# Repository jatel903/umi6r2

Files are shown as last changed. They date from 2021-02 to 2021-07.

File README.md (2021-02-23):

# UMI6R2
## Universal modbus inputs module
###### jatel.sk
**Specification:**  
Supply: 12 - 30V / 50mA  
Core: Arduino Nano  
Number of inputs: 6  
Input types: TTL / TTL with pull-up 2k2 / 0-10V / 1-10V / 0-20mA / 4-20mA  
Number of outputs: 2  
Output types: relay contact 10A/240VAC  
Communication: Modbus RTU 485  
Mounting: [DIN 4M](https://www.tme.eu/sk/en/details/4mh53_5/din-rail-mounting-enclosures/italtronic/)  

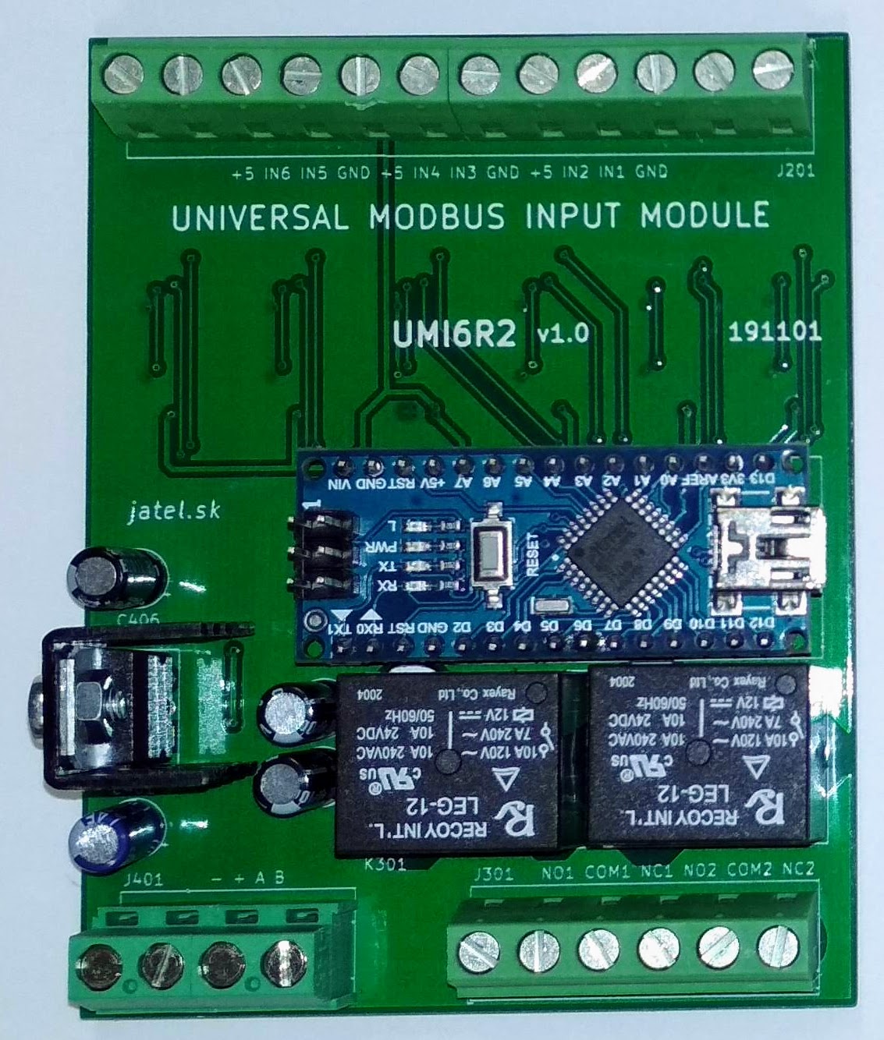
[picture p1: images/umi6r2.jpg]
  

#### Description
Low cost universal modbus controll unit for low cost sensors and actuators from China:  
[NTC](https://www.aliexpress.com/item/1005001645557005.html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,searchweb201602_,searchweb201603_)  
 [Hall Flow Sensor](https://www.aliexpress.com/item/1005001652070023.html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,searchweb201602_,searchweb201603_)  
[DHT22](https://www.aliexpress.com/item/32759901711.html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,searchweb201602_,searchweb201603_)  
[DS18B20](https://www.aliexpress.com/item/4000895660165.html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,searchweb201602_,searchweb201603_)  
[Pressure Sensor](https://www.aliexpress.com/item/1447040260.html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,searchweb201602_,searchweb201603_)  
[Electric Valve](https://www.aliexpress.com/item/4000279793000.html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,searchweb201602_,searchweb201603_)  
[Electric Solenoid Valve](https://www.aliexpress.com/item/4000067341651.html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,searchweb201602_,searchweb201603_)  
etc...

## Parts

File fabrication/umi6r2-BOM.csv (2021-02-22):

Reference | Quantity | Value | Footprint | Datasheet
A401 | 1 | Arduino_Nano_v3.x | Module:Arduino_Nano | http://www.mouser.com/pdfdocs/Gravitech_Arduino_Nano3_0.pdf
C201 C202 C203 C213 C214 C215 | 6 | 100p | Capacitor_SMD:C_0805_2012Metric_Pad1.15x1.40mm_HandSolder | ~
C210 C204 C205 C211 C206 C207 C212 C208 C209 C222 C216 C217 C223 C218 C219 C224 C220 C221 C405 C402 C403 C408 C407 C404 | 24 | 100n | Capacitor_SMD:C_0805_2012Metric_Pad1.15x1.40mm_HandSolder | ~
C301 C302 C406 | 3 | 100u/16V | Capacitor_THT:CP_Radial_D5.0mm_P2.50mm | ~
C401 | 1 | 47u/35V | Capacitor_THT:CP_Radial_D5.0mm_P2.50mm | ~
D201 D202 D203 D204 D205 D206 | 6 | BZT52B5V6 | Diode_SMD:D_SOD-123 | https://diotec.com/tl_files/diotec/files/pdf/datasheets/bzt52b2v4.pdf
D301 D302 | 2 | TS4148 | Diode_SMD:D_0805_2012Metric
D401 | 1 | B140-E3 | Diode_SMD:D_SMA | http://www.vishay.com/docs/88946/b120.pdf
F201 F202 F203 F204 F205 F206 | 6 | SN005 | Resistor_SMD:R_1206_3216Metric_Pad1.42x1.75mm_HandSolder | ~
J201 | 1 | INPUTS | TerminalBlock_Phoenix:TerminalBlock_Phoenix_MKDS-1,5-12-5.08_1x12_P5.08mm_Horizontal | ~
J301 | 1 | OUTPUTS | TerminalBlock_Phoenix:TerminalBlock_Phoenix_MKDS-1,5-6-5.08_1x06_P5.08mm_Horizontal | ~
J401 | 1 | Pwr | TerminalBlock_Phoenix:TerminalBlock_Phoenix_MKDS-1,5-4-5.08_1x04_P5.08mm_Horizontal | ~
K301 K302 | 2 | LEG-12 | jt_relay:Relay_SPDT_RAYEX ELEC_LEG_Series_Form_1C | https://www.tme.eu/Document/311affc211749c2a4c93ad074af62b72/LEG-SERIES.pdf
Q301 Q302 | 2 | BC847 | Package_TO_SOT_SMD:SOT-23 | http://www.infineon.com/dgdl/Infineon-BC847SERIES_BC848SERIES_BC849SERIES_BC850SERIES-DS-v01_01-en.pdf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
R202 R201 R204 R203 R206 R205 R226 R225 R228 R227 R230 R229 | 12 | 100R | Resistor_SMD:R_0805_2012Metric_Pad1.15x1.40mm_HandSolder | ~
R207 R210 R212 R215 R217 R220 R231 R234 R236 R239 R241 R244 R401 | 13 | 12k | Resistor_SMD:R_0805_2012Metric_Pad1.15x1.40mm_HandSolder | ~
R209 R208 R214 R213 R219 R218 R233 R232 R238 R237 R243 R242 | 12 | 3k3 | Resistor_SMD:R_0805_2012Metric_Pad1.15x1.40mm_HandSolder | ~
R211 R216 R221 R235 R240 R245 | 6 | 51R | Resistor_SMD:R_0805_2012Metric_Pad1.15x1.40mm_HandSolder | ~
R222 R223 R224 R246 R247 R248 | 6 | 2R7 | Resistor_SMD:R_0805_2012Metric_Pad1.15x1.40mm_HandSolder | ~
R303 R304 | 2 | 330R | Resistor_SMD:R_0805_2012Metric_Pad1.15x1.40mm_HandSolder | ~
R305 R301 R306 R302 | 4 | 4k7 | Resistor_SMD:R_0805_2012Metric_Pad1.15x1.40mm_HandSolder | ~
U201 U202 U203 U204 U205 U206 | 6 | 74HC4052 | Package_SO:SOIC-16_3.9x9.9mm_P1.27mm | http://www.ti.com/lit/ds/symlink/cd4052b.pdf
U401 | 1 | MAX485E | Package_SO:SOIC-8_3.9x4.9mm_P1.27mm | https://datasheets.maximintegrated.com/en/ds/MAX1487E-MAX491E.pdf
U402 | 1 | LM7812_TO220 | Package_TO_SOT_THT:TO-220-3_Vertical | http://www.fairchildsemi.com/ds/LM/LM7805.pdf
U403 | 1 | 74HC595 | Package_SO:SOIC-16_3.9x9.9mm_P1.27mm | http://www.ti.com/lit/ds/symlink/sn74hc595.pdf

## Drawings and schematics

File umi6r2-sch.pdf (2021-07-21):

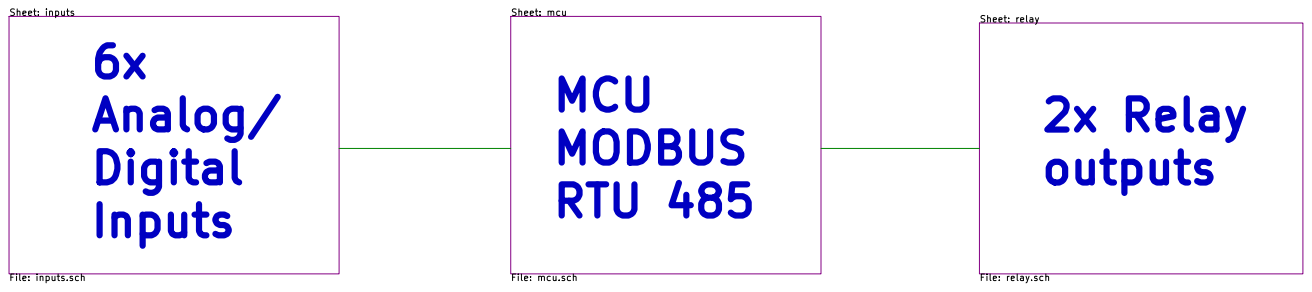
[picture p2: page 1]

File: relay.sch Sheet: mcu File: mcu.schMCU

Id: 1/4 Title: File: umi6r2.sch Sheet: /

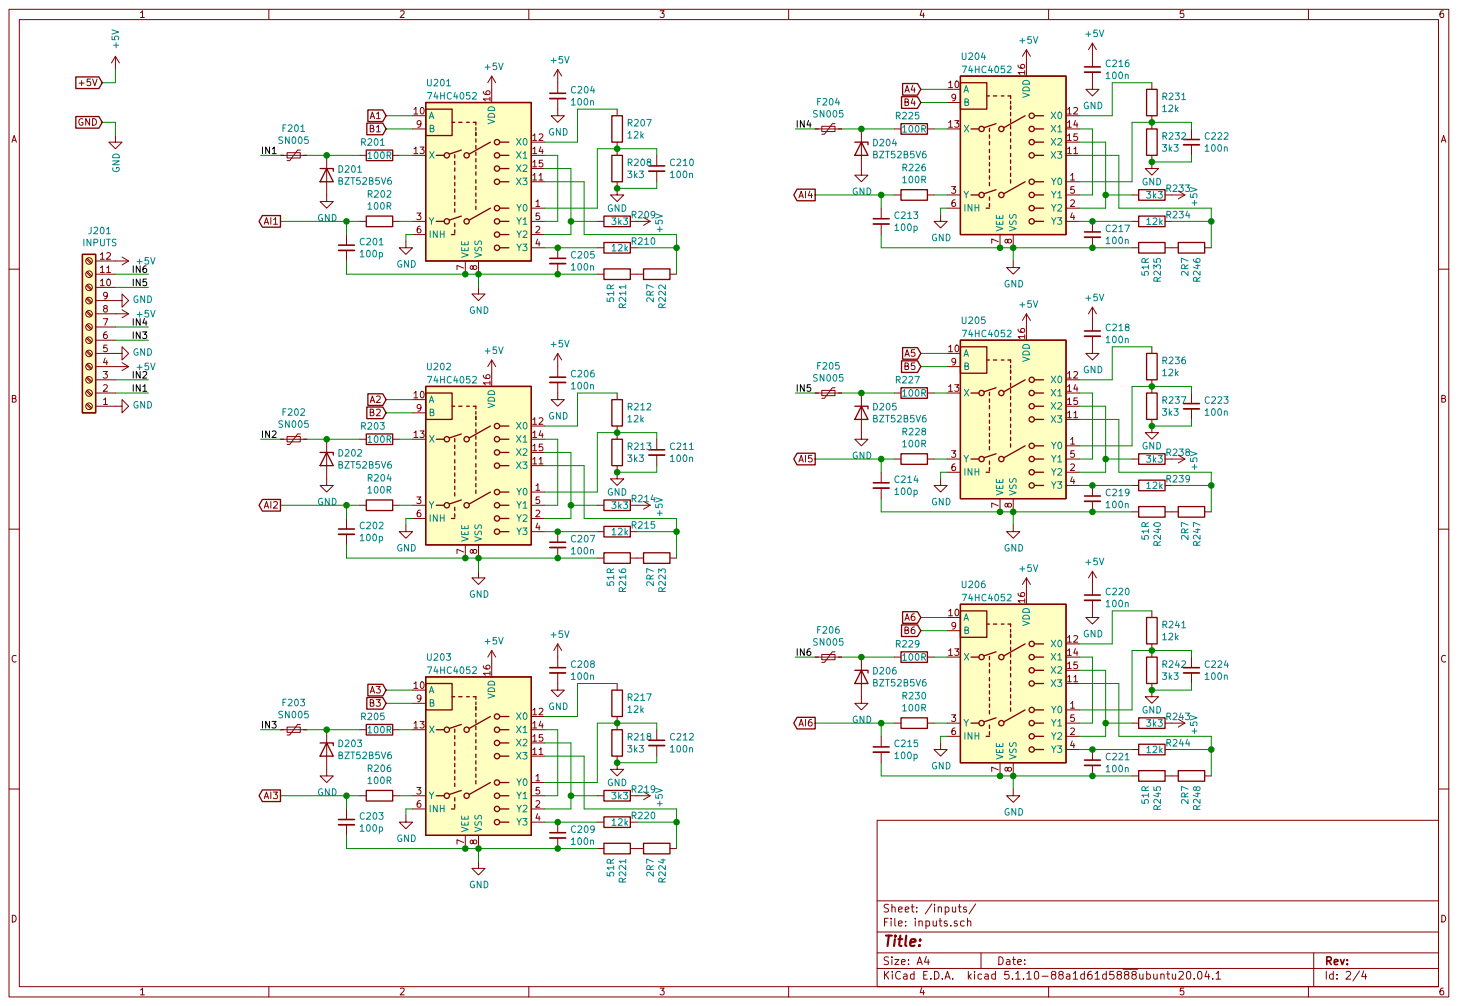
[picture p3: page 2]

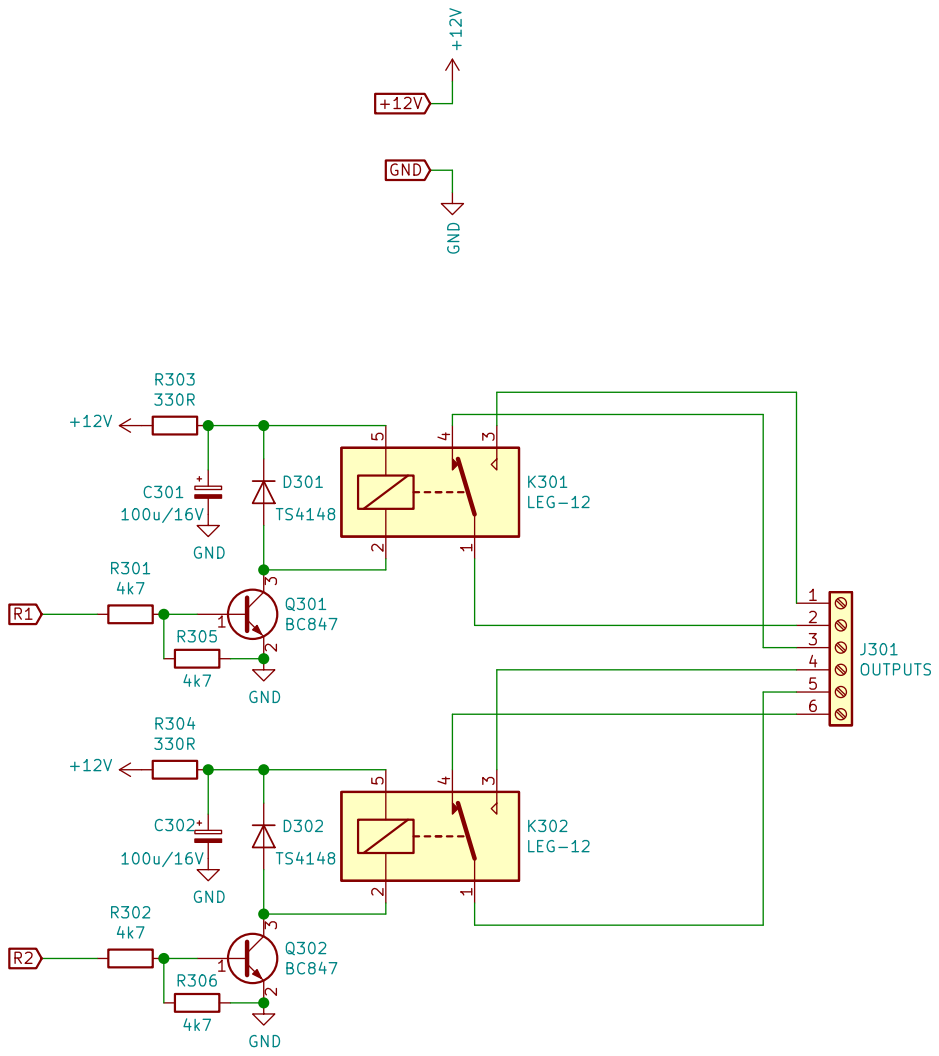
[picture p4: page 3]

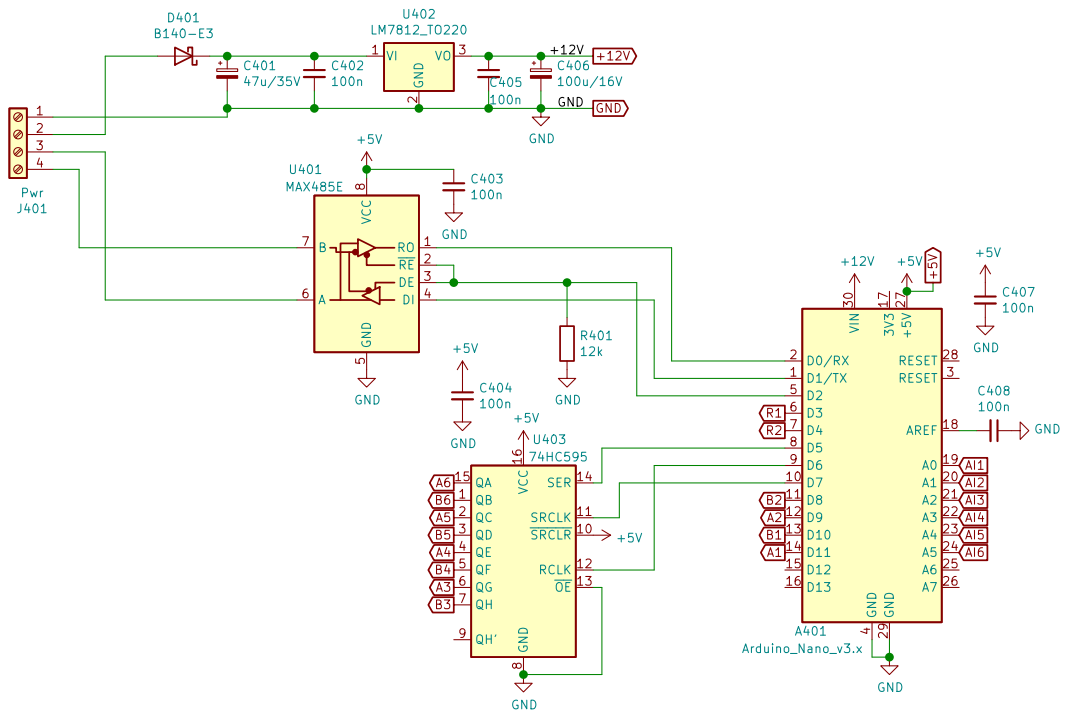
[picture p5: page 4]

Id: 4/4 Title: File: mcu.sch Sheet: /mcu/

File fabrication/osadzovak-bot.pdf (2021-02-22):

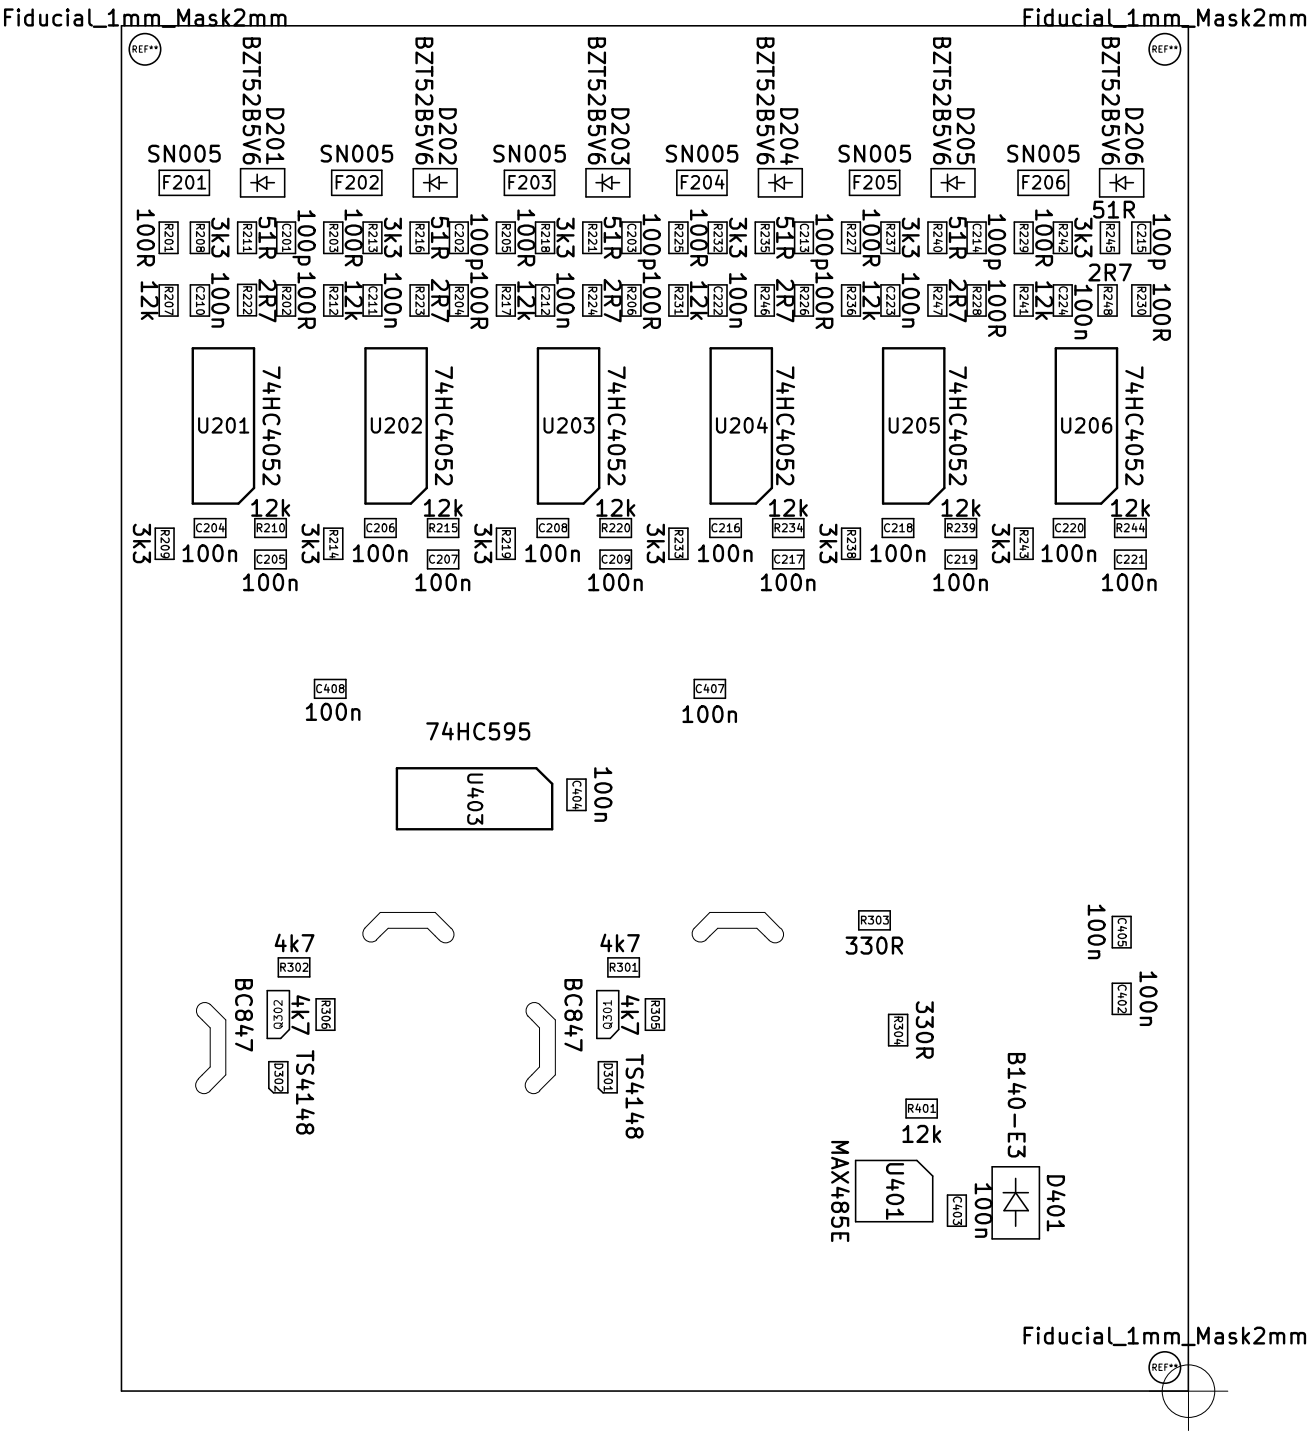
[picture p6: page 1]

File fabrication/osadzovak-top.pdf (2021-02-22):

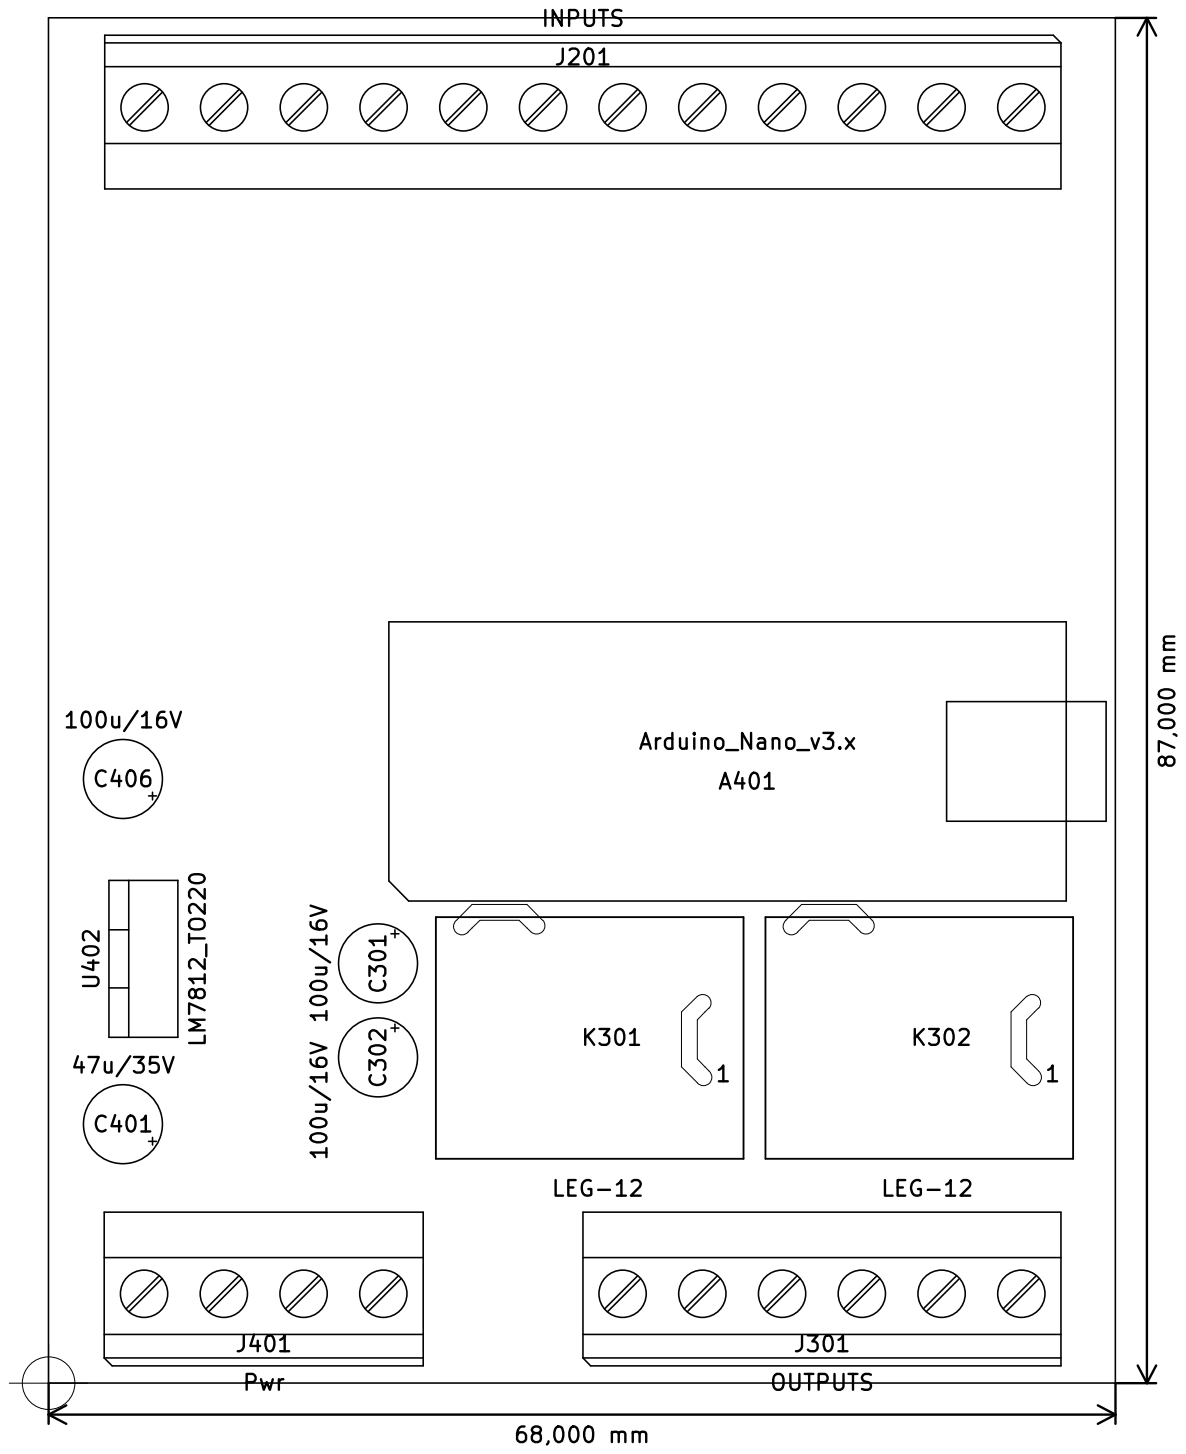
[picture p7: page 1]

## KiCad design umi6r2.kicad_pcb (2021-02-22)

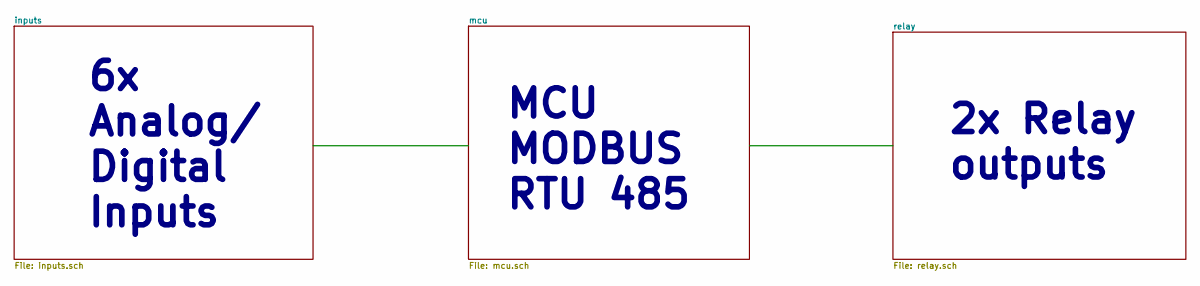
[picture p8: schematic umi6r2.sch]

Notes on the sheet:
MCU MODBUS RTU 485
2x Relay outputs
6x Analog/ Digital Inputs

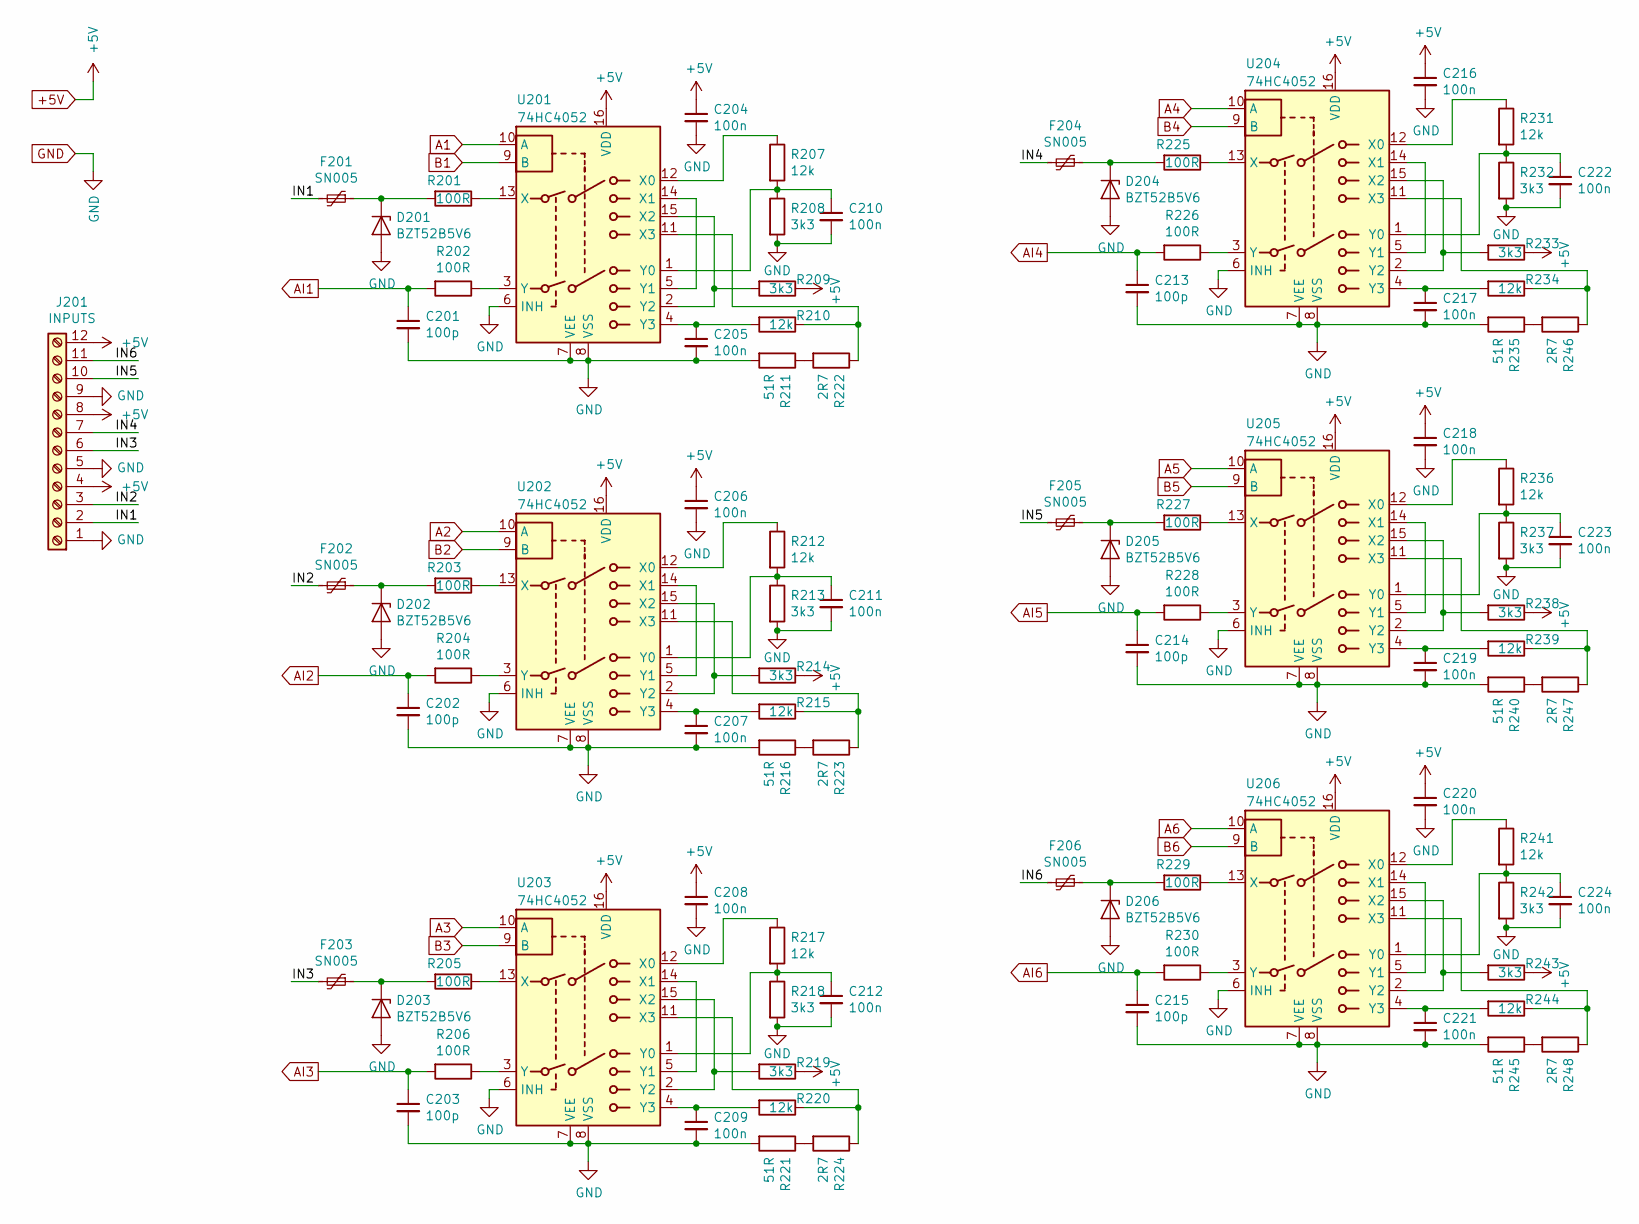
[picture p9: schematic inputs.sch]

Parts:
C201, C202, C203, C213, C214, C215: 100p; C_0805_2012Metric_Pad1.15x1.40mm_HandSolder
C204, C205, C206, C207, C208, C209, C210, C211, C212, C216, C217, C218, C219, C220, C221, C222, C223, C224: 100n; C_0805_2012Metric_Pad1.15x1.40mm_HandSolder
D201, D202, D203, D204, D205, D206: BZT52B5V6; D_SOD-123
F201, F202, F203, F204, F205, F206: SN005; R_1206_3216Metric_Pad1.42x1.75mm_HandSolder
J201: INPUTS; TerminalBlock_Phoenix_MKDS-1,5-12-5.08_1x12_P5.08mm_Horizon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
R201, R202, R203, R204, R205, R206, R225, R226, R227, R228, R229, R230: 100R; R_0805_2012Metric_Pad1.15x1.40mm_HandSolder
R207, R210, R212, R215, R217, R220, R231, R234, R236, R239, R241, R244: 12k; R_0805_2012Metric_Pad1.15x1.40mm_HandSolder
R208, R209, R213, R214, R218, R219, R232, R233, R237, R238, R242, R243: 3k3; R_0805_2012Metric_Pad1.15x1.40mm_HandSolder
R211, R216, R221, R235, R240, R245: 51R; R_0805_2012Metric_Pad1.15x1.40mm_HandSolder
R222, R223, R224, R246, R247, R248: 2R7; R_0805_2012Metric_Pad1.15x1.40mm_HandSolder
U201, U202, U203, U204, U205, U206: 74HC4052; SOIC-16_3.9x9.9mm_P1.27mm

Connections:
+5V: C204.1, C206.1, C208.1, C216.1, C218.1, C220.1, J201.4, J201.8, J201.12, R209.1, R214.1, R219.1, R233.1, R238.1, R243.1, U201.16 (VDD), U202.16 (VDD), U203.16 (VDD), U204.16 (VDD), U205.16 (VDD), U206.16 (VDD); also elsewhere on the board
/inputs/IN1: F201.2, J201.2
/inputs/IN2: F202.2, J201.3
/inputs/IN3: F203.2, J201.6
/inputs/IN4: F204.2, J201.7
/inputs/IN5: F205.2, J201.10
/inputs/IN6: F206.2, J201.11
A1: U201.10 (A); also elsewhere on the board
A2: U202.10 (A); also elsewhere on the board
A3: U203.10 (A); also elsewhere on the board
A4: U204.10 (A); also elsewhere on the board
A5: U205.10 (A); also elsewhere on the board
A6: U206.10 (A); also elsewhere on the board
AI1: C201.1, R202.2; also elsewhere on the board
AI2: C202.1, R204.2; also elsewhere on the board
AI3: C203.1, R206.2; also elsewhere on the board
AI4: C213.1, R226.2; also elsewhere on the board
AI5: C214.1, R228.2; also elsewhere on the board
AI6: C215.1, R230.2; also elsewhere on the board
B1: U201.9 (B); also elsewhere on the board
B2: U202.9 (B); also elsewhere on the board
B3: U203.9 (B); also elsewhere on the board
B4: U204.9 (B); also elsewhere on the board
B5: U205.9 (B); also elsewhere on the board
B6: U206.9 (B); also elsewhere on the board
GND: C201.2, C202.2, C203.2, C204.2, C205.2, C206.2, C207.2, C208.2, C209.2, C210.2, C211.2, C212.2, C213.2, C214.2, C215.2, C216.2, C217.2, C218.2, C219.2, C220.2, C221.2, C222.2, C223.2, C224.2, D201.2 (A), D202.2 (A), D203.2 (A), D204.2 (A), D205.2 (A), D206.2 (A), J201.1, J201.5, J201.9, R208.2, R211.2, R213.2, R216.2, R218.2, R221.2, R232.2, R235.2, R237.2, R240.2, R242.2, R245.2, U201.6 (INH), U201.7 (VEE), U201.8 (VSS), U202.6 (INH), U202.7 (VEE), U202.8 (VSS), U203.6 (INH), U203.7 (VEE), U203.8 (VSS), U204.6 (INH), U204.7 (VEE), U204.8 (VSS), U205.6 (INH), U205.7 (VEE), U205.8 (VSS), U206.6 (INH), U206.7 (VEE), U206.8 (VSS); also elsewhere on the board
unnamed: C205.1, R210.2, U201.4 (Y3)
unnamed: C207.1, R215.2, U202.4 (Y3)
unnamed: C209.1, R220.2, U203.4 (Y3)
unnamed: C210.1, R207.2, R208.1, U201.1 (Y0)
unnamed: C211.1, R212.2, R213.1, U202.1 (Y0)
unnamed: C212.1, R217.2, R218.1, U203.1 (Y0)
unnamed: C217.1, R234.2, U204.4 (Y3)
unnamed: C219.1, R239.2, U205.4 (Y3)
unnamed: C221.1, R244.2, U206.4 (Y3)
unnamed: C222.1, R231.2, R232.1, U204.1 (Y0)
unnamed: C223.1, R236.2, R237.1, U205.1 (Y0)
unnamed: C224.1, R241.2, R242.1, U206.1 (Y0)
unnamed: D201.1 (K), F201.1, R201.2
unnamed: D202.1 (K), F202.1, R203.2
unnamed: D203.1 (K), F203.1, R205.2
unnamed: D204.1 (K), F204.1, R225.2
unnamed: D205.1 (K), F205.1, R227.2
unnamed: D206.1 (K), F206.1, R229.2
unnamed: R201.1, U201.13 (X)
unnamed: R202.1, U201.3 (Y)
unnamed: R203.1, U202.13 (X)
unnamed: R204.1, U202.3 (Y)
unnamed: R205.1, U203.13 (X)
unnamed: R206.1, U203.3 (Y)
unnamed: R207.1, U201.12 (X0)
unnamed: R209.2, U201.2 (Y2), U201.15 (X2)
unnamed: R210.1, R222.1, U201.11 (X3)
unnamed: R211.1, R222.2
unnamed: R212.1, U202.12 (X0)
unnamed: R214.2, U202.2 (Y2), U202.15 (X2)
unnamed: R215.1, R223.1, U202.11 (X3)
unnamed: R216.1, R223.2
unnamed: R217.1, U203.12 (X0)
unnamed: R219.2, U203.2 (Y2), U203.15 (X2)
unnamed: R220.1, R224.1, U203.11 (X3)
unnamed: R221.1, R224.2
unnamed: R225.1, U204.13 (X)
unnamed: R226.1, U204.3 (Y)
unnamed: R227.1, U205.13 (X)
unnamed: R228.1, U205.3 (Y)
unnamed: R229.1, U206.13 (X)
unnamed: R230.1, U206.3 (Y)
unnamed: R231.1, U204.12 (X0)
unnamed: R233.2, U204.2 (Y2), U204.15 (X2)
unnamed: R234.1, R246.1, U204.11 (X3)
unnamed: R235.1, R246.2
unnamed: R236.1, U205.12 (X0)
unnamed: R238.2, U205.2 (Y2), U205.15 (X2)
unnamed: R239.1, R247.1, U205.11 (X3)
unnamed: R240.1, R247.2
unnamed: R241.1, U206.12 (X0)
unnamed: R243.2, U206.2 (Y2), U206.15 (X2)
unnamed: R244.1, R248.1, U206.11 (X3)
unnamed: R245.1, R248.2
unnamed: U201.5 (Y1), U201.14 (X1)
unnamed: U202.5 (Y1), U202.14 (X1)
unnamed: U203.5 (Y1), U203.14 (X1)
unnamed: U204.5 (Y1), U204.14 (X1)
unnamed: U205.5 (Y1), U205.14 (X1)
unnamed: U206.5 (Y1), U206.14 (X1)

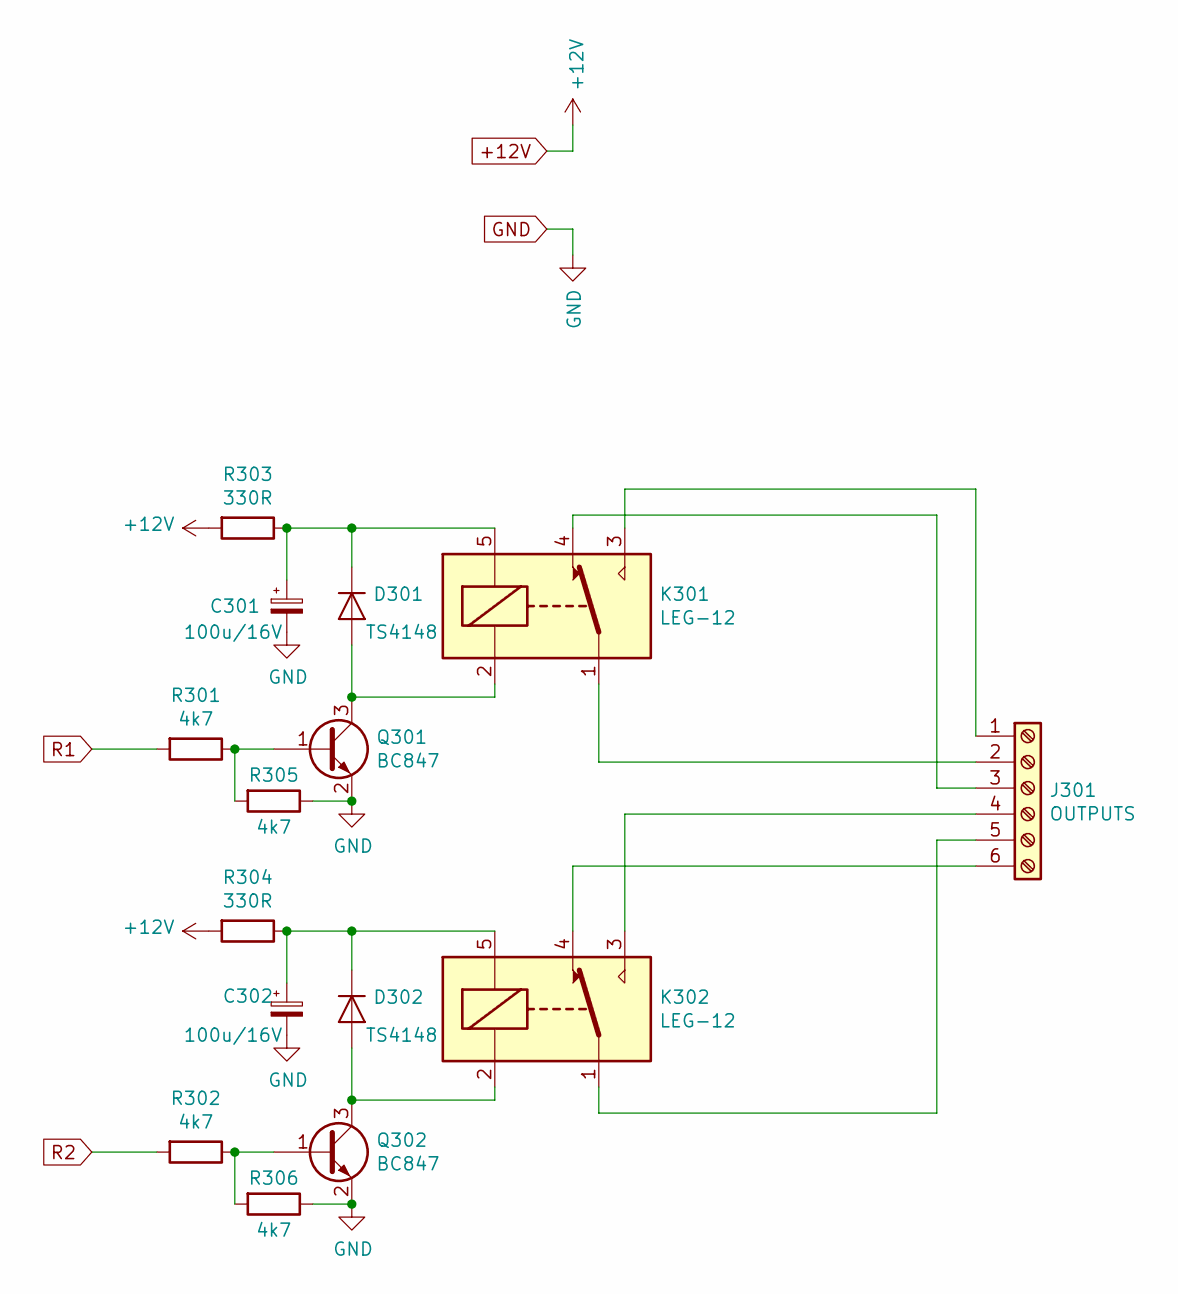
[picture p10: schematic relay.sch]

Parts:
C301, C302: 100u/16V; CP_Radial_D5.0mm_P2.50mm
D301, D302: TS4148; D_0805_2012Metric
J301: OUTPUTS; TerminalBlock_Phoenix_MKDS-1,5-6-5.08_1x06_P5.08mm_Horizont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
K301, K302: LEG-12; Relay_SPDT_RAYEX ELEC_LEG_Series_Form_1C
Q301, Q302: BC847; SOT-23
R301, R302, R305, R306: 4k7; R_0805_2012Metric_Pad1.15x1.40mm_HandSolder
R303, R304: 330R; R_0805_2012Metric_Pad1.15x1.40mm_HandSolder

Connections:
+12V: R303.2, R304.2; also elsewhere on the board
GND: C301.2, C302.2, Q301.2 (E), Q302.2 (E), R305.1, R306.1; also elsewhere on the board
unnamed: C301.1, D301.1 (K), K301.5 (coil), R303.1
unnamed: C302.1, D302.1 (K), K302.5 (coil), R304.1
unnamed: D301.2 (A), K301.2 (coil), Q301.3 (C)
unnamed: D302.2 (A), K302.2 (coil), Q302.3 (C)
unnamed: J301.1, K301.3 (NO)
unnamed: J301.2, K301.1 (com)
unnamed: J301.3, K301.4 (NC)
unnamed: J301.4, K302.3 (NO)
unnamed: J301.5, K302.1 (com)
unnamed: J301.6, K302.4 (NC)
unnamed: Q301.1 (B), R301.1, R305.2
unnamed: Q302.1 (B), R302.1, R306.2
R1: R301.2; also elsewhere on the board
R2: R302.2; also elsewhere on the board

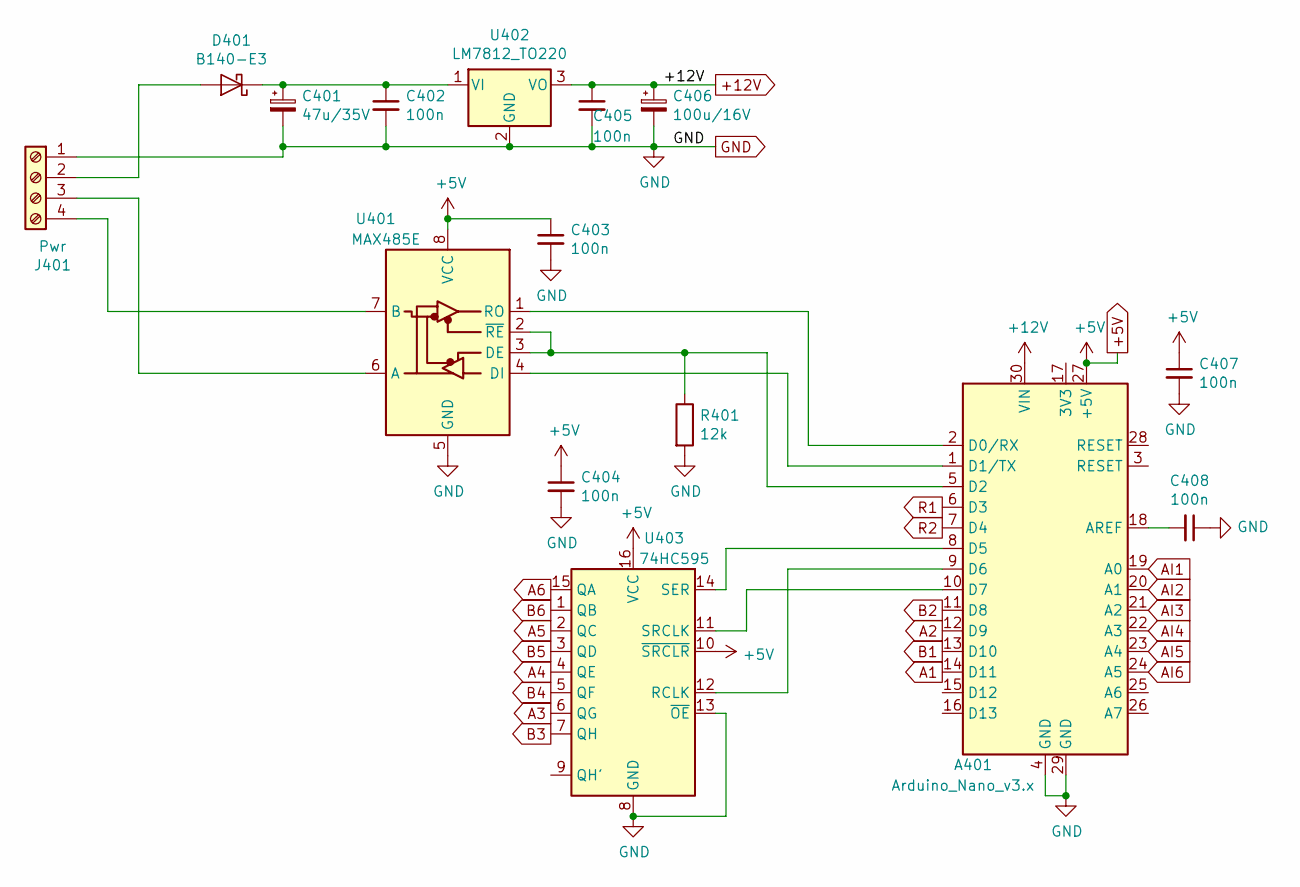
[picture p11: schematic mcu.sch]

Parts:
A401: Arduino_Nano_v3.x; Arduino_Nano
C401: 47u/35V; CP_Radial_D5.0mm_P2.50mm
C402, C403, C404, C405, C407, C408: 100n; C_0805_2012Metric_Pad1.15x1.40mm_HandSolder
C406: 100u/16V; CP_Radial_D5.0mm_P2.50mm
D401: B140-E3; D_SMA
J401: Pwr; TerminalBlock_Phoenix_MKDS-1,5-4-5.08_1x04_P5.08mm_Horizont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
R401: 12k; R_0805_2012Metric_Pad1.15x1.40mm_HandSolder
U401: MAX485E; SOIC-8_3.9x4.9mm_P1.27mm
U402: LM7812_TO220; TO-220-3_Vertical
U403: 74HC595; SOIC-16_3.9x9.9mm_P1.27mm

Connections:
+5V: A401.27 (+5V), C403.1, C404.1, C407.1, U401.8 (VCC), U403.10 (~SRCLR), U403.16 (VCC); also elsewhere on the board
+12V: A401.30 (VIN), C405.1, C406.1, U402.3 (VO); also elsewhere on the board
A1: A401.14 (D11); also elsewhere on the board
A2: A401.12 (D9); also elsewhere on the board
A3: U403.6 (QG); also elsewhere on the board
A4: U403.4 (QE); also elsewhere on the board
A5: U403.2 (QC); also elsewhere on the board
A6: U403.15 (QA); also elsewhere on the board
AI1: A401.19 (A0); also elsewhere on the board
AI2: A401.20 (A1); also elsewhere on the board
AI3: A401.21 (A2); also elsewhere on the board
AI4: A401.22 (A3); also elsewhere on the board
AI5: A401.23 (A4); also elsewhere on the board
AI6: A401.24 (A5); also elsewhere on the board
B1: A401.13 (D10); also elsewhere on the board
B2: A401.11 (D8); also elsewhere on the board
B3: U403.7 (QH); also elsewhere on the board
B4: U403.5 (QF); also elsewhere on the board
B5: U403.3 (QD); also elsewhere on the board
B6: U403.1 (QB); also elsewhere on the board
GND: A401.4 (GND), A401.29 (GND), C401.2, C402.2, C403.2, C404.2, C405.2, C406.2, C407.2, C408.1, J401.1, R401.2, U401.5 (GND), U402.2 (GND), U403.8 (GND), U403.13 (~OE); also elsewhere on the board
unnamed: A401.1 (D1/TX), U401.4 (DI)
unnamed: A401.2 (D0/RX), U401.1 (RO)
unnamed: A401.5 (D2), R401.1, U401.2 (~RE), U401.3 (DE)
unnamed: A401.8 (D5), U403.14 (SER)
unnamed: A401.9 (D6), U403.12 (RCLK)
unnamed: A401.10 (D7), U403.11 (SRCLK)
unnamed: A401.18 (AREF), C408.2
unnamed: C401.1, C402.1, D401.1 (K), U402.1 (VI)
unnamed: D401.2 (A), J401.2
unnamed: J401.3, U401.6 (A)
unnamed: J401.4, U401.7 (B)
R1: A401.6 (D3); also elsewhere on the board
R2: A401.7 (D4); also elsewhere on the board

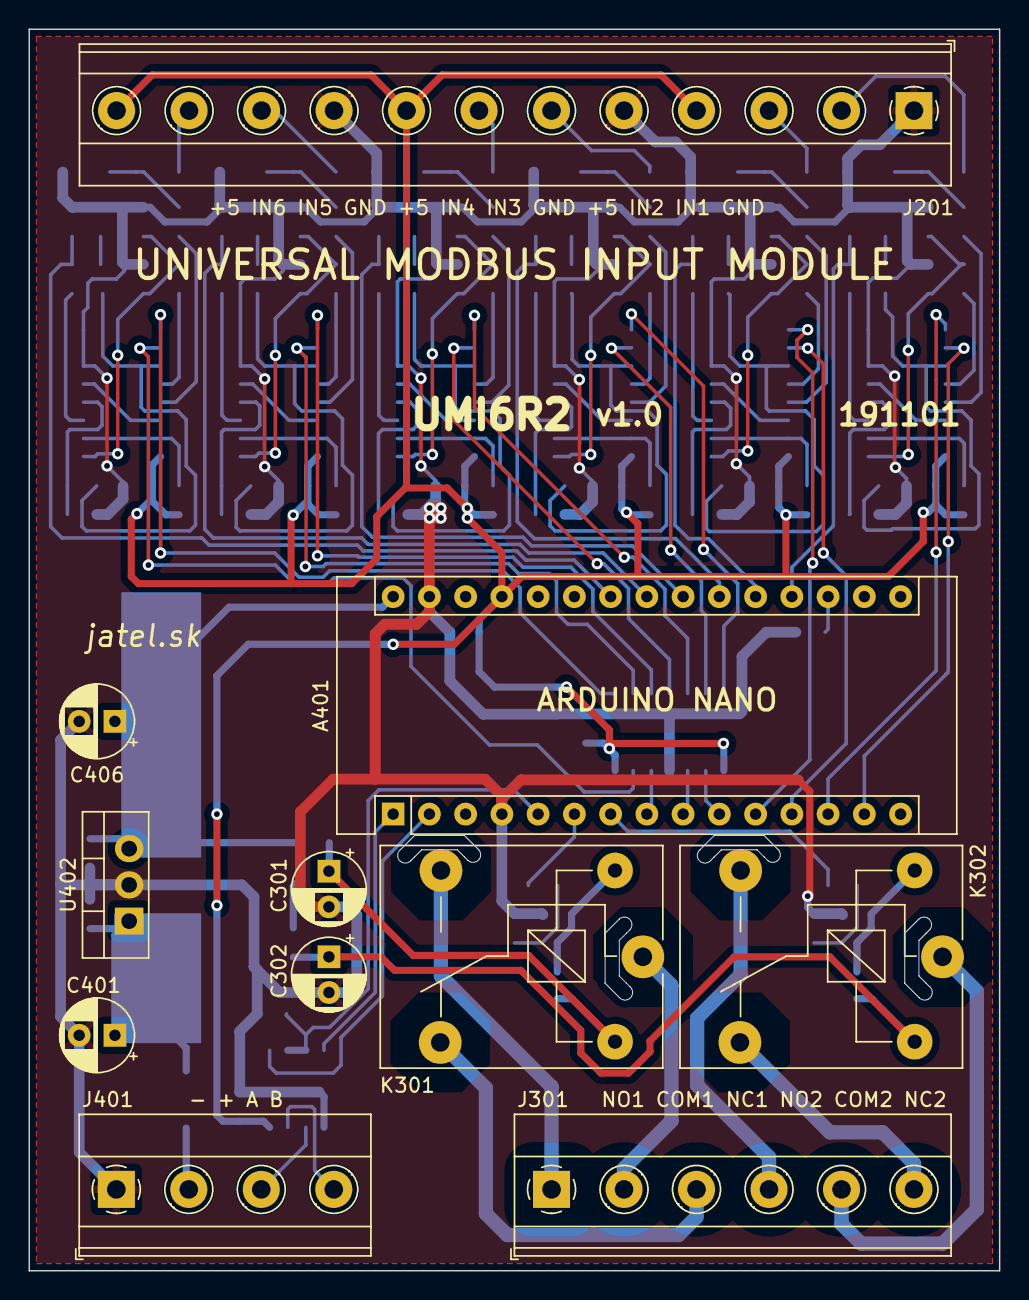
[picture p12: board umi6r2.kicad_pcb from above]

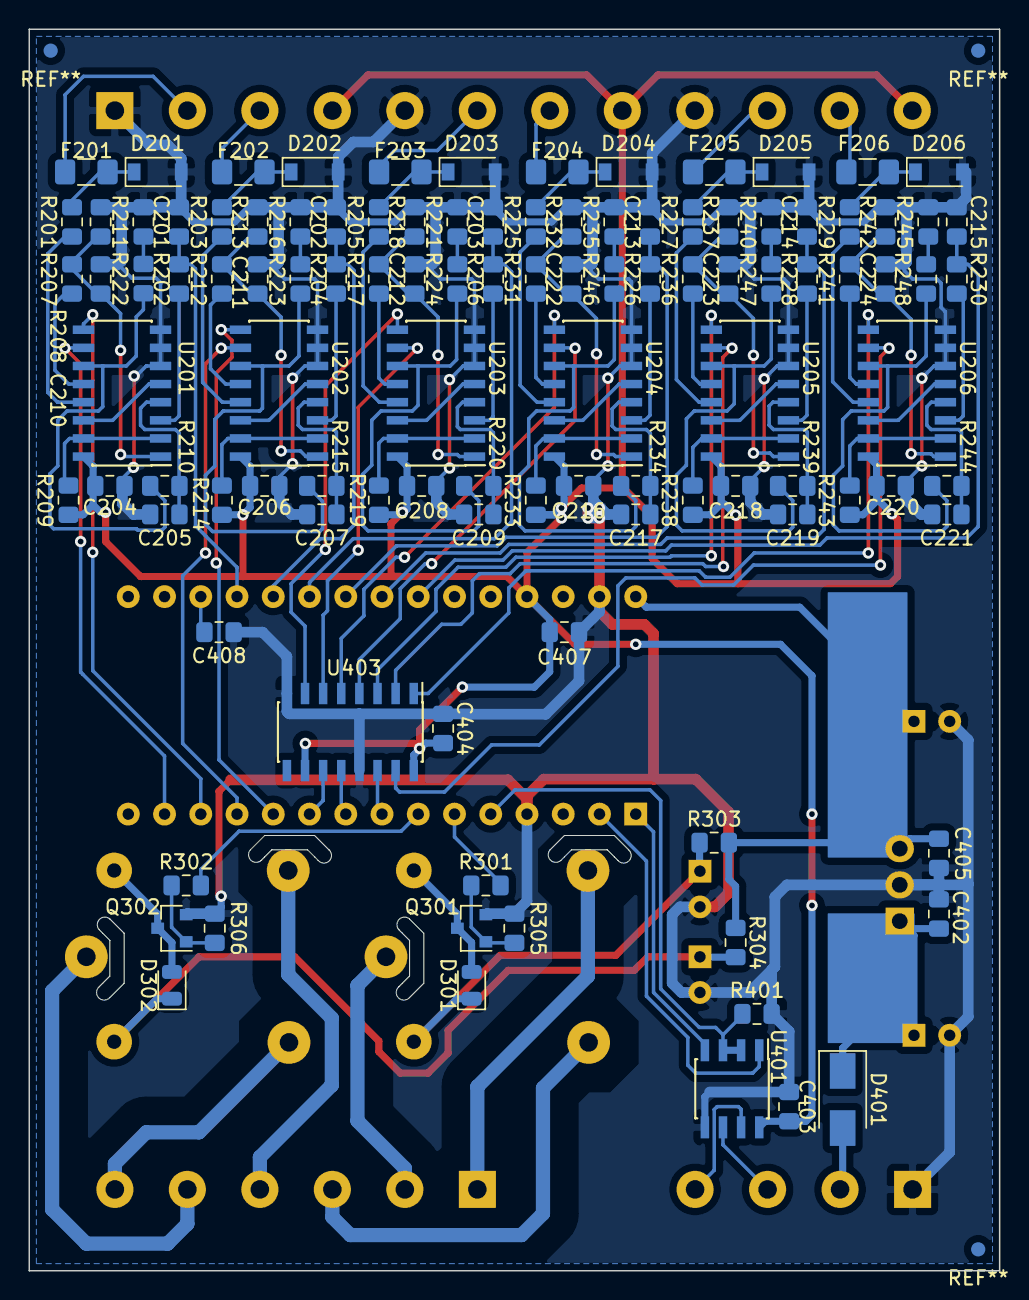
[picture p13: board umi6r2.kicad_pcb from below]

Board: 2 copper layers, 68.0 x 87.0 mm, 121 parts (110 on the bottom side), 112 nets.
